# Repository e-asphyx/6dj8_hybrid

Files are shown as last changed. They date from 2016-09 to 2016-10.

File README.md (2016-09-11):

# DC coupled hybrid headphone amplifier
The input stage was inspired by Cavalli’s SOHA-II, but I have choose different output design. I use source follower loaded to Norton level shifter fed by op amp DC servo (inspired by TI’s LME49600 reference design) via current mirror to drive simple MOSFET source follower with SSC.

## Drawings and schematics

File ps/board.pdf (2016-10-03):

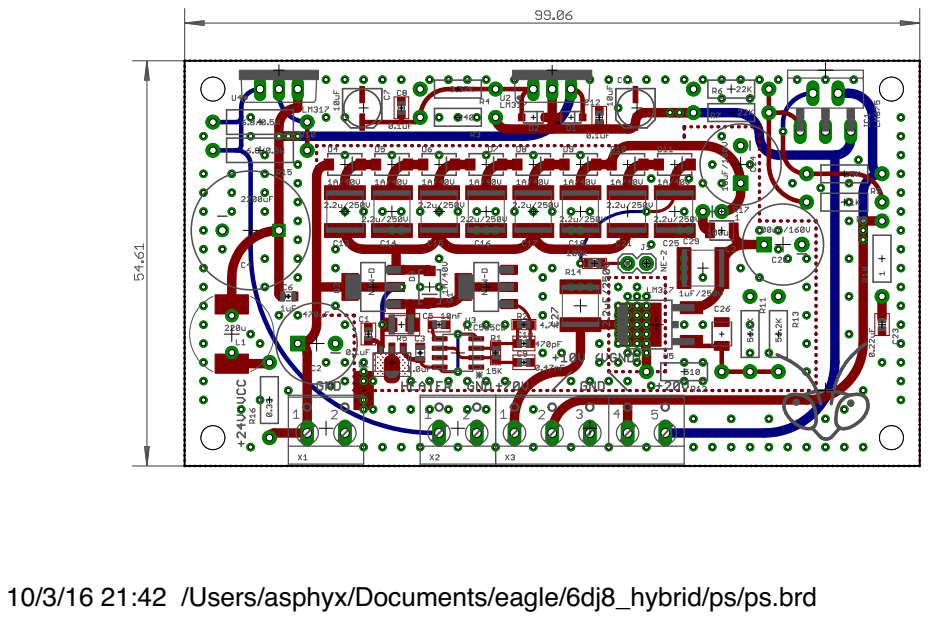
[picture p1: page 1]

10/3/16 21:42 /Users/asphyx/Documents/eagle/6dj8_hybrid/ps/ps.brd

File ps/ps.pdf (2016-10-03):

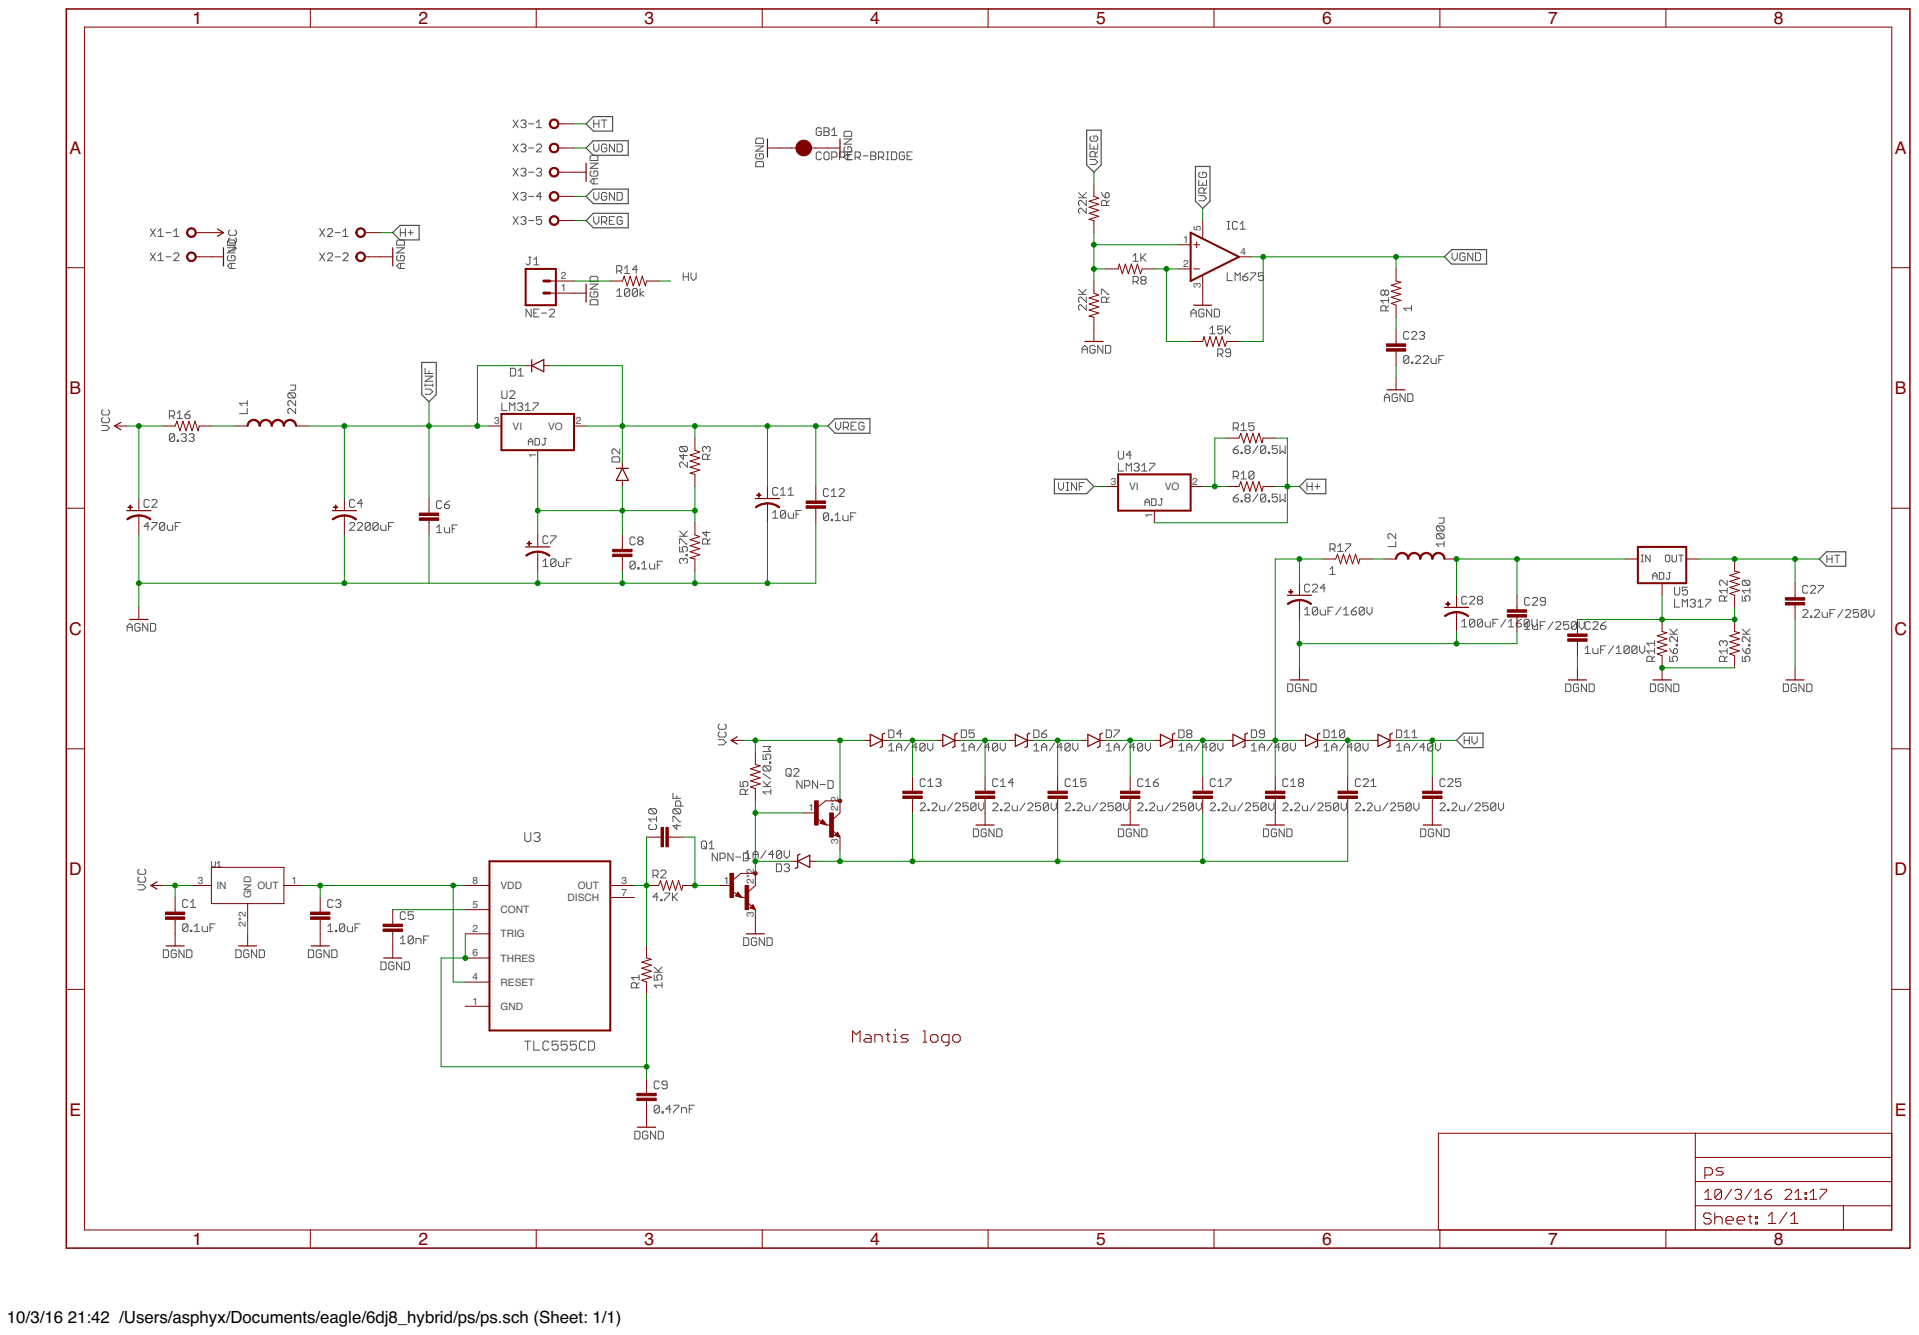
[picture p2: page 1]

10/3/16 21:42 /Users/asphyx/Documents/eagle/6dj8_hybrid/ps/ps.sch (Sheet: 1/1)

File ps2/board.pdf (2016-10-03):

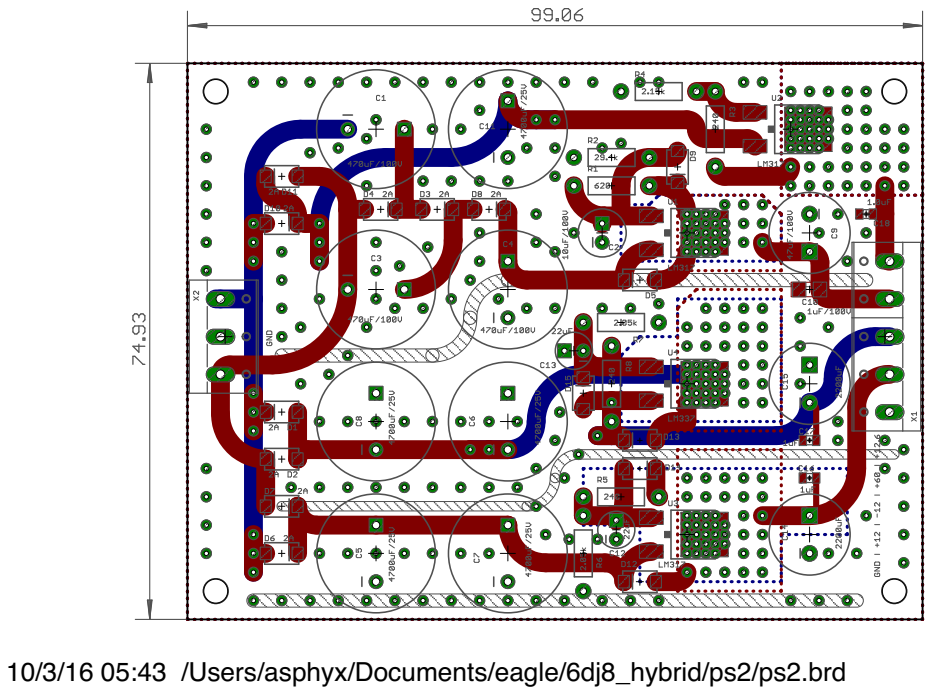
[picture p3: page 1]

10/3/16 05:43 /Users/asphyx/Documents/eagle/6dj8_hybrid/ps2/ps2.brd

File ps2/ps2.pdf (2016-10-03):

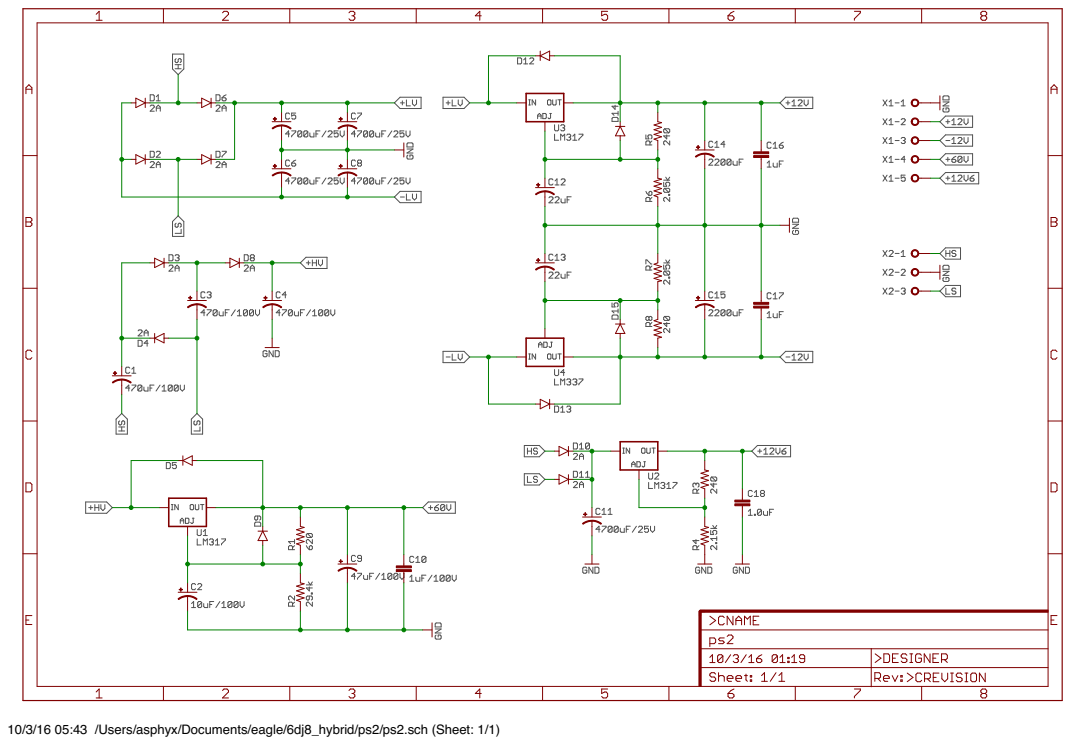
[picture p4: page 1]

10/3/16 05:43 /Users/asphyx/Documents/eagle/6dj8_hybrid/ps2/ps2.sch (Sheet: 1/1)

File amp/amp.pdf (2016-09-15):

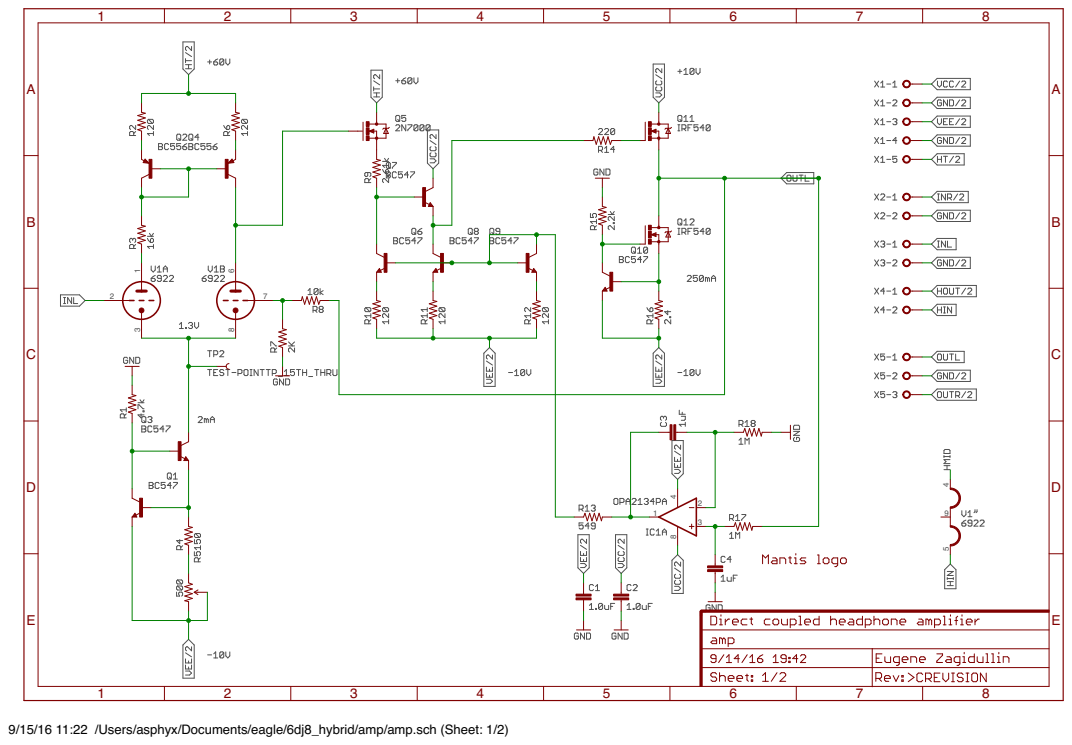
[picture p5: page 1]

9/15/16 11:22 /Users/asphyx/Documents/eagle/6dj8_hybrid/amp/amp.sch (Sheet: 1/2)

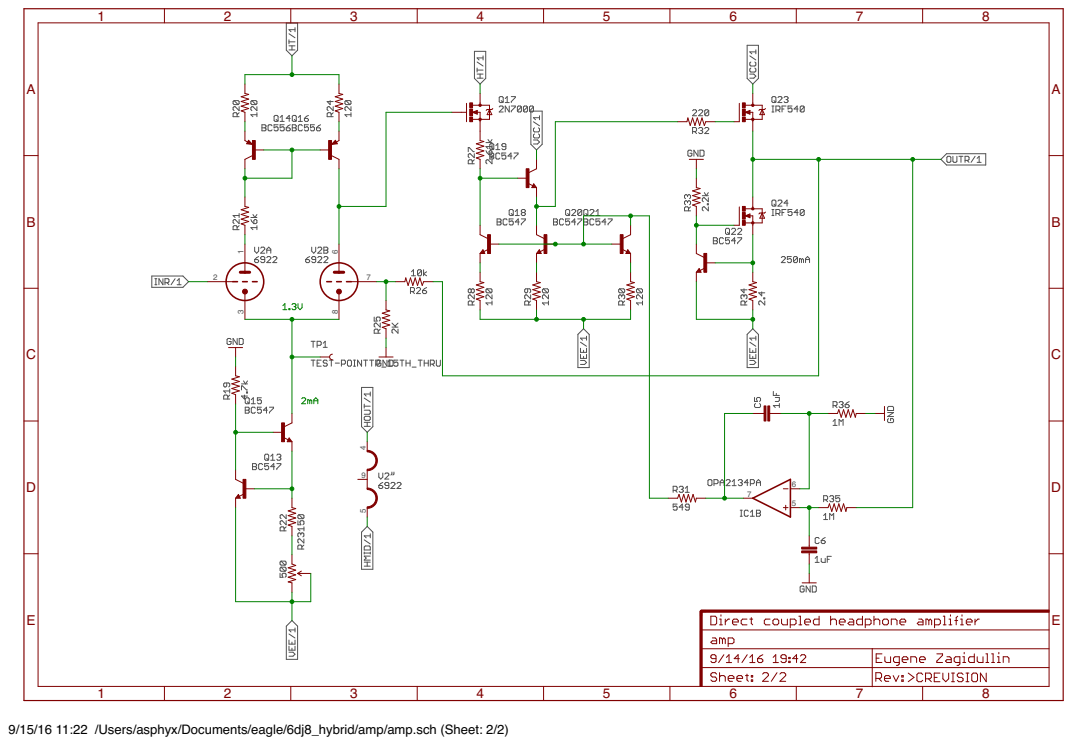
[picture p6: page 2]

9/15/16 11:22 /Users/asphyx/Documents/eagle/6dj8_hybrid/amp/amp.sch (Sheet: 2/2)

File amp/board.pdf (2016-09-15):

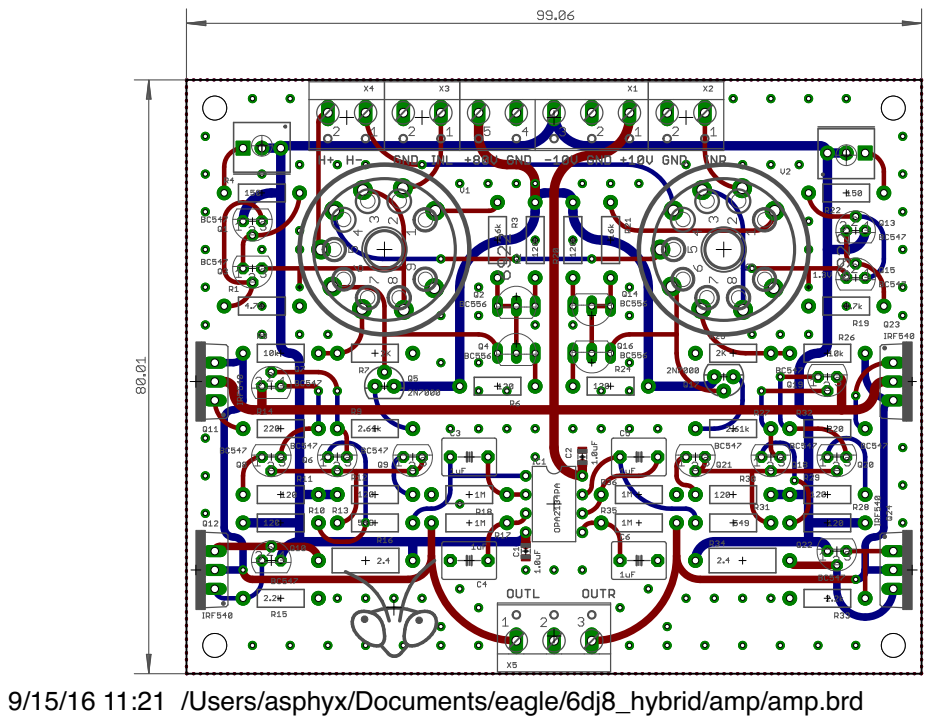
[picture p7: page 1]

9/15/16 11:21 /Users/asphyx/Documents/eagle/6dj8_hybrid/amp/amp.brd

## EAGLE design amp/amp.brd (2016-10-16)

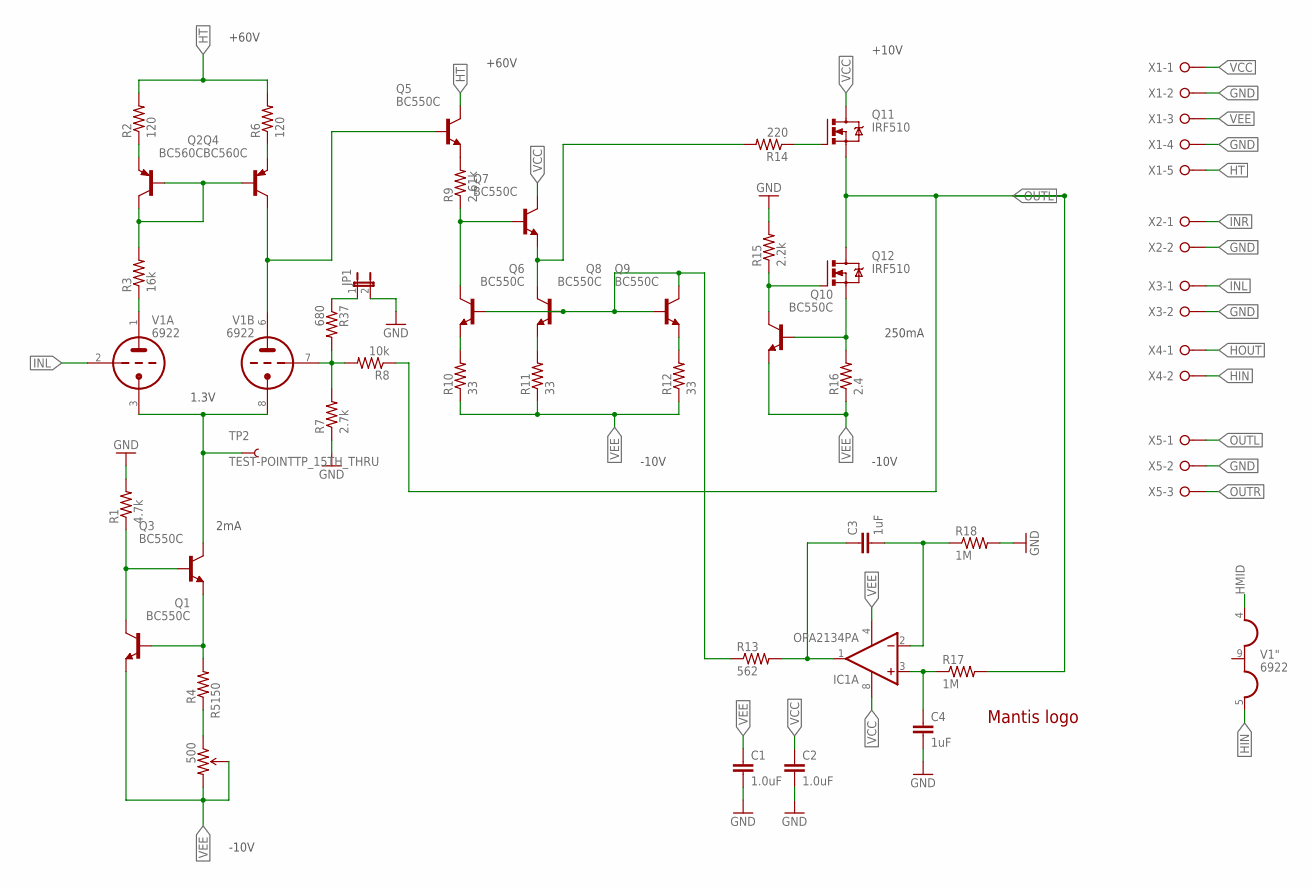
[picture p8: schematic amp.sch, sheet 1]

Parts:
C1, C2: 1.0uF; 0805-CAP
C3, C4: 1uF; C5B5
IC1: OPA2134PA; DIL08
JP1: JUMPER-2PTH; 1X02
LOGO1: LOGO-MANTIS
Q1, Q3, Q5, Q6, Q7, Q8, Q9, Q10: BC550C; TO92
Q2, Q4: BC560C; TO92-BENT
Q11, Q12: IRF510; TO220BV
R1: 4.7k; AXIAL-0.4
R2, R6: 120; AXIAL-0.4
R3: 16k; AXIAL-0.4
R4: 150; AXIAL-0.4
R5: 500; 3362U-2
R7: 2.7k; AXIAL-0.4
R8: 10k; AXIAL-0.4
R9: 2.61k; AXIAL-0.4
R10, R11, R12: 33; AXIAL-0.4
R13: 562; AXIAL-0.4
R14: 220; AXIAL-0.4
R15: 2.2k; AXIAL-0.4
R16: 2.4; AXIAL-0.5
R17, R18: 1M; AXIAL-0.4
R37: 680; AXIAL-0.4
TP2: TEST-POINTTP_15TH_THRU; TP_15TH
V1: 6922; NOVAL
X1: W237-05P; W237-5P
X2, X3, X4: W237-02P; W237-132
X5: W237-3E

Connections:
GND: C1.2, C2.2, C4.2, JP1.2, R1.P$2 (2), R7.P$1 (1), R15.P$2 (2), R18.P$2 (2), X1.2, X1.4, X2.2, X3.2, X5.2; also elsewhere on the board
HIN: V1.5 (H3), X4.2
HMID: V1.4 (H1); also elsewhere on the board
HOUT: X4.1; also elsewhere on the board
HT: Q5.3 (C), R2.P$2 (2), R6.P$2 (2), X1.5; also elsewhere on the board
INL: V1.2 (TG), X3.1
INR: X2.1; also elsewhere on the board
unnamed: Q3.3 (C), TP2.P$1, V1.3 (TK), V1.8 (TK)
unnamed: Q2.1 (C), Q2.2 (B), Q4.2 (B), R3.P$2 (2)
unnamed: Q2.3 (E), R2.P$1 (1)
unnamed: Q4.1 (C), Q5.2 (B), V1.6 (TA)
unnamed: R3.P$1 (1), V1.1 (TA)
unnamed: Q4.3 (E), R6.P$1 (1)
unnamed: Q1.2 (B), Q3.1 (E), R4.P$2 (2)
unnamed: Q1.3 (C), Q3.2 (B), R1.P$1 (1)
unnamed: R7.P$2 (2), R8.P$2 (2), R37.P$2 (2), V1.7 (TG)
unnamed: Q6.2 (B), Q8.2 (B), Q9.2 (B), Q9.3 (C), R13.P$1 (1)
unnamed: Q6.1 (E), R10.P$2 (2)
unnamed: Q9.1 (E), R12.P$2 (2)
unnamed: Q5.1 (E), R9.P$2 (2)
unnamed: Q10.3 (C), Q12.G, R15.P$1 (1)
unnamed: Q10.2 (B), Q12.S, R16.P$2 (2)
unnamed: C3.2, IC1.2 (-IN), R18.P$1 (1)
unnamed: C4.1, IC1.3 (+IN), R17.P$1 (1)
unnamed: C3.1, IC1.1 (OUT), R13.P$2 (2)
unnamed: Q8.1 (E), R11.P$2 (2)
unnamed: R4.P$1 (1), R5.1 (CCW)
unnamed: Q11.G, R14.P$1 (1)
unnamed: Q6.3 (C), Q7.2 (B), R9.P$1 (1)
unnamed: Q7.1 (E), Q8.3 (C), R14.P$2 (2)
unnamed: JP1.1, R37.P$1 (1)
OUTL: Q11.S, Q12.D, R8.P$1 (1), R17.P$2 (2), X5.1
OUTR: X5.3; also elsewhere on the board
VCC: C2.1, IC1.8 (V+), Q7.3 (C), Q11.D, X1.1; also elsewhere on the board
VEE: C1.1, IC1.4 (V-), Q1.1 (E), Q10.1 (E), R5.2 (WIPER), R5.3 (CW), R10.P$1 (1), R11.P$1 (1), R12.P$1 (1), R16.P$1 (1), X1.3; also elsewhere on the board

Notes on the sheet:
2mA
250mA
1.3V
+60V
+10V
-10V

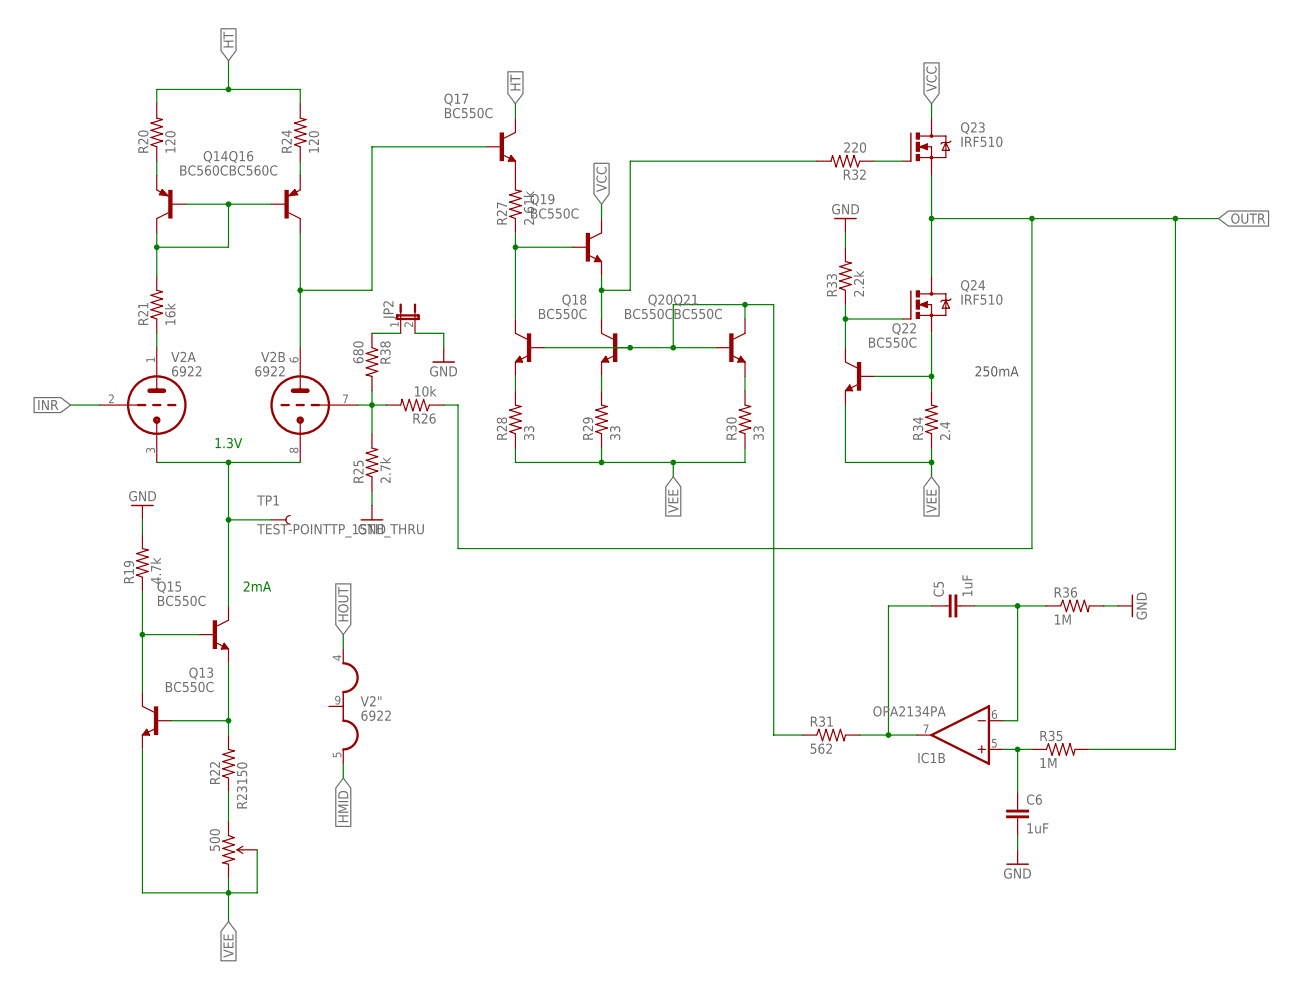
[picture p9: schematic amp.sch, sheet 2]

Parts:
C5, C6: 1uF; C5B5
IC1: OPA2134PA; DIL08
JP2: JUMPER-2PTH; 1X02
Q13, Q15, Q17, Q18, Q19, Q20, Q21, Q22: BC550C; TO92
Q14, Q16: BC560C; TO92-BENT
Q23, Q24: IRF510; TO220BV
R19: 4.7k; AXIAL-0.4
R20, R24: 120; AXIAL-0.4
R21: 16k; AXIAL-0.4
R22: 150; AXIAL-0.4
R23: 500; 3362U-2
R25: 2.7k; AXIAL-0.4
R26: 10k; AXIAL-0.4
R27: 2.61k; AXIAL-0.4
R28, R29, R30: 33; AXIAL-0.4
R31: 562; AXIAL-0.4
R32: 220; AXIAL-0.4
R33: 2.2k; AXIAL-0.4
R34: 2.4; AXIAL-0.5
R35, R36: 1M; AXIAL-0.4
R38: 680; AXIAL-0.4
TP1: TEST-POINTTP_15TH_THRU; TP_15TH
V2: 6922; NOVAL

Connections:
GND: C6.2, JP2.2, R19.P$2 (2), R25.P$1 (1), R33.P$2 (2), R36.P$2 (2); also elsewhere on the board
HMID: V2.5 (H3); also elsewhere on the board
HOUT: V2.4 (H1); also elsewhere on the board
HT: Q17.3 (C), R20.P$2 (2), R24.P$2 (2); also elsewhere on the board
INR: V2.2 (TG); also elsewhere on the board
unnamed: Q18.3 (C), Q19.2 (B), R27.P$1 (1)
unnamed: Q15.3 (C), TP1.P$1, V2.3 (TK), V2.8 (TK)
unnamed: Q14.1 (C), Q14.2 (B), Q16.2 (B), R21.P$2 (2)
unnamed: Q16.1 (C), Q17.2 (B), V2.6 (TA)
unnamed: R21.P$1 (1), V2.1 (TA)
unnamed: Q14.3 (E), R20.P$1 (1)
unnamed: Q16.3 (E), R24.P$1 (1)
unnamed: Q13.2 (B), Q15.1 (E), R22.P$2 (2)
unnamed: Q13.3 (C), Q15.2 (B), R19.P$1 (1)
unnamed: Q18.2 (B), Q20.2 (B), Q21.2 (B), Q21.3 (C), R31.P$1 (1)
unnamed: Q18.1 (E), R28.P$2 (2)
unnamed: Q21.1 (E), R30.P$2 (2)
unnamed: Q19.1 (E), Q20.3 (C), R32.P$2 (2)
unnamed: Q22.3 (C), Q24.G, R33.P$1 (1)
unnamed: Q22.2 (B), Q24.S, R34.P$2 (2)
unnamed: R25.P$2 (2), R26.P$2 (2), R38.P$2 (2), V2.7 (TG)
unnamed: C5.2, IC1.6 (-IN), R36.P$1 (1)
unnamed: C6.1, IC1.5 (+IN), R35.P$1 (1)
unnamed: C5.1, IC1.7 (OUT), R31.P$2 (2)
unnamed: R22.P$1 (1), R23.1 (CCW)
unnamed: Q23.G, R32.P$1 (1)
unnamed: Q17.1 (E), R27.P$2 (2)
unnamed: Q20.1 (E), R29.P$2 (2)
unnamed: JP2.1, R38.P$1 (1)
OUTR: Q23.S, Q24.D, R26.P$1 (1), R35.P$2 (2); also elsewhere on the board
VCC: Q19.3 (C), Q23.D; also elsewhere on the board
VEE: Q13.1 (E), Q22.1 (E), R23.2 (WIPER), R23.3 (CW), R28.P$1 (1), R29.P$1 (1), R30.P$1 (1), R34.P$1 (1); also elsewhere on the board

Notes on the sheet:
2mA
250mA
1.3V

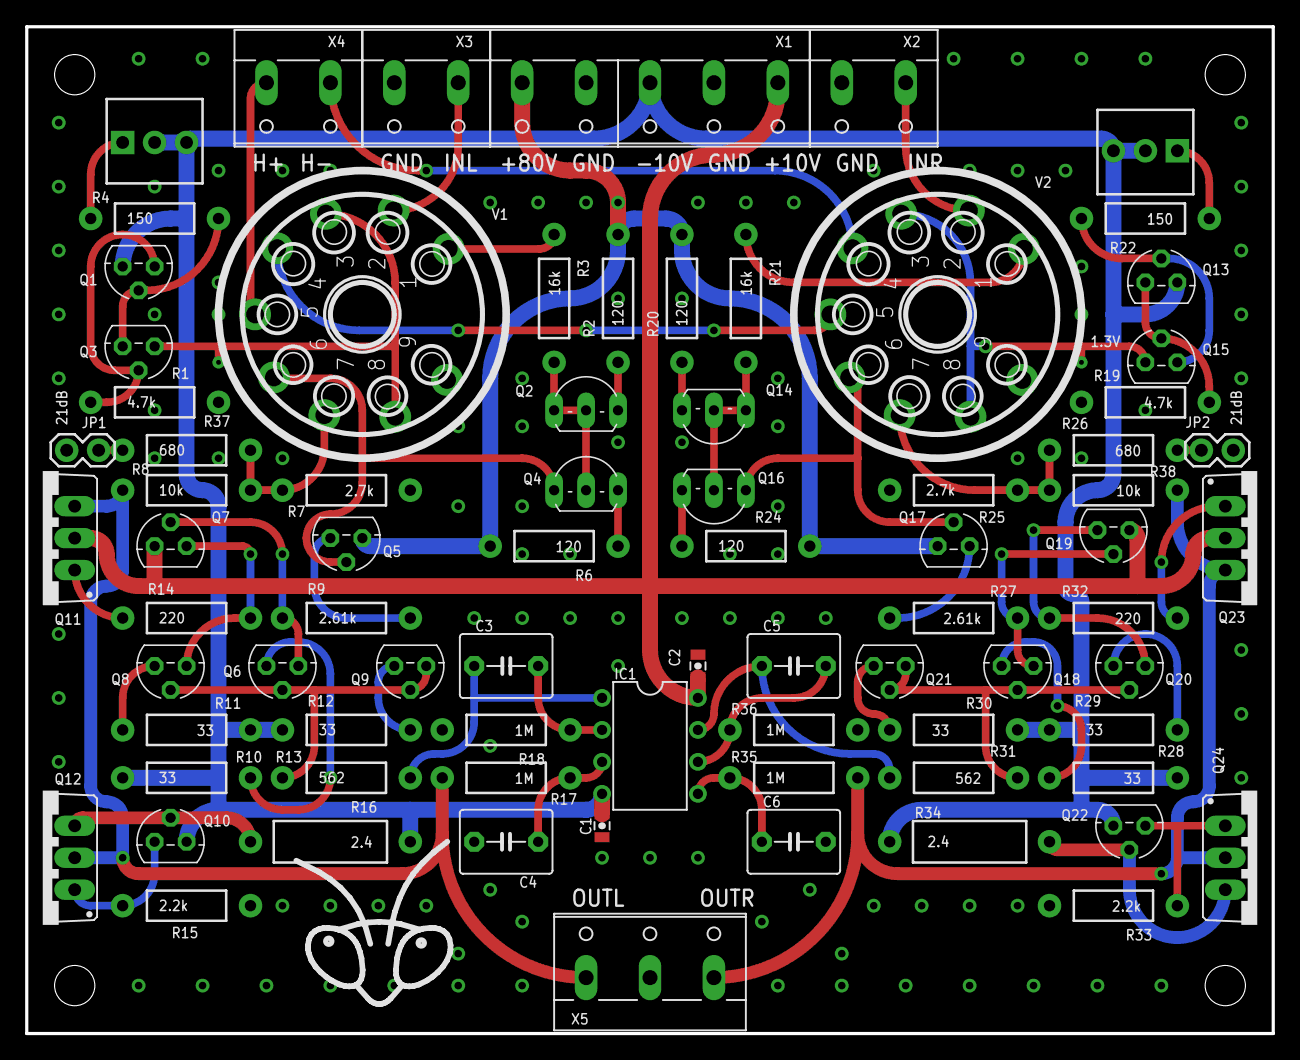
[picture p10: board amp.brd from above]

Board: 2 copper layers, 99.1 x 80.0 mm, 81 parts (0 on the bottom side), 59 nets.

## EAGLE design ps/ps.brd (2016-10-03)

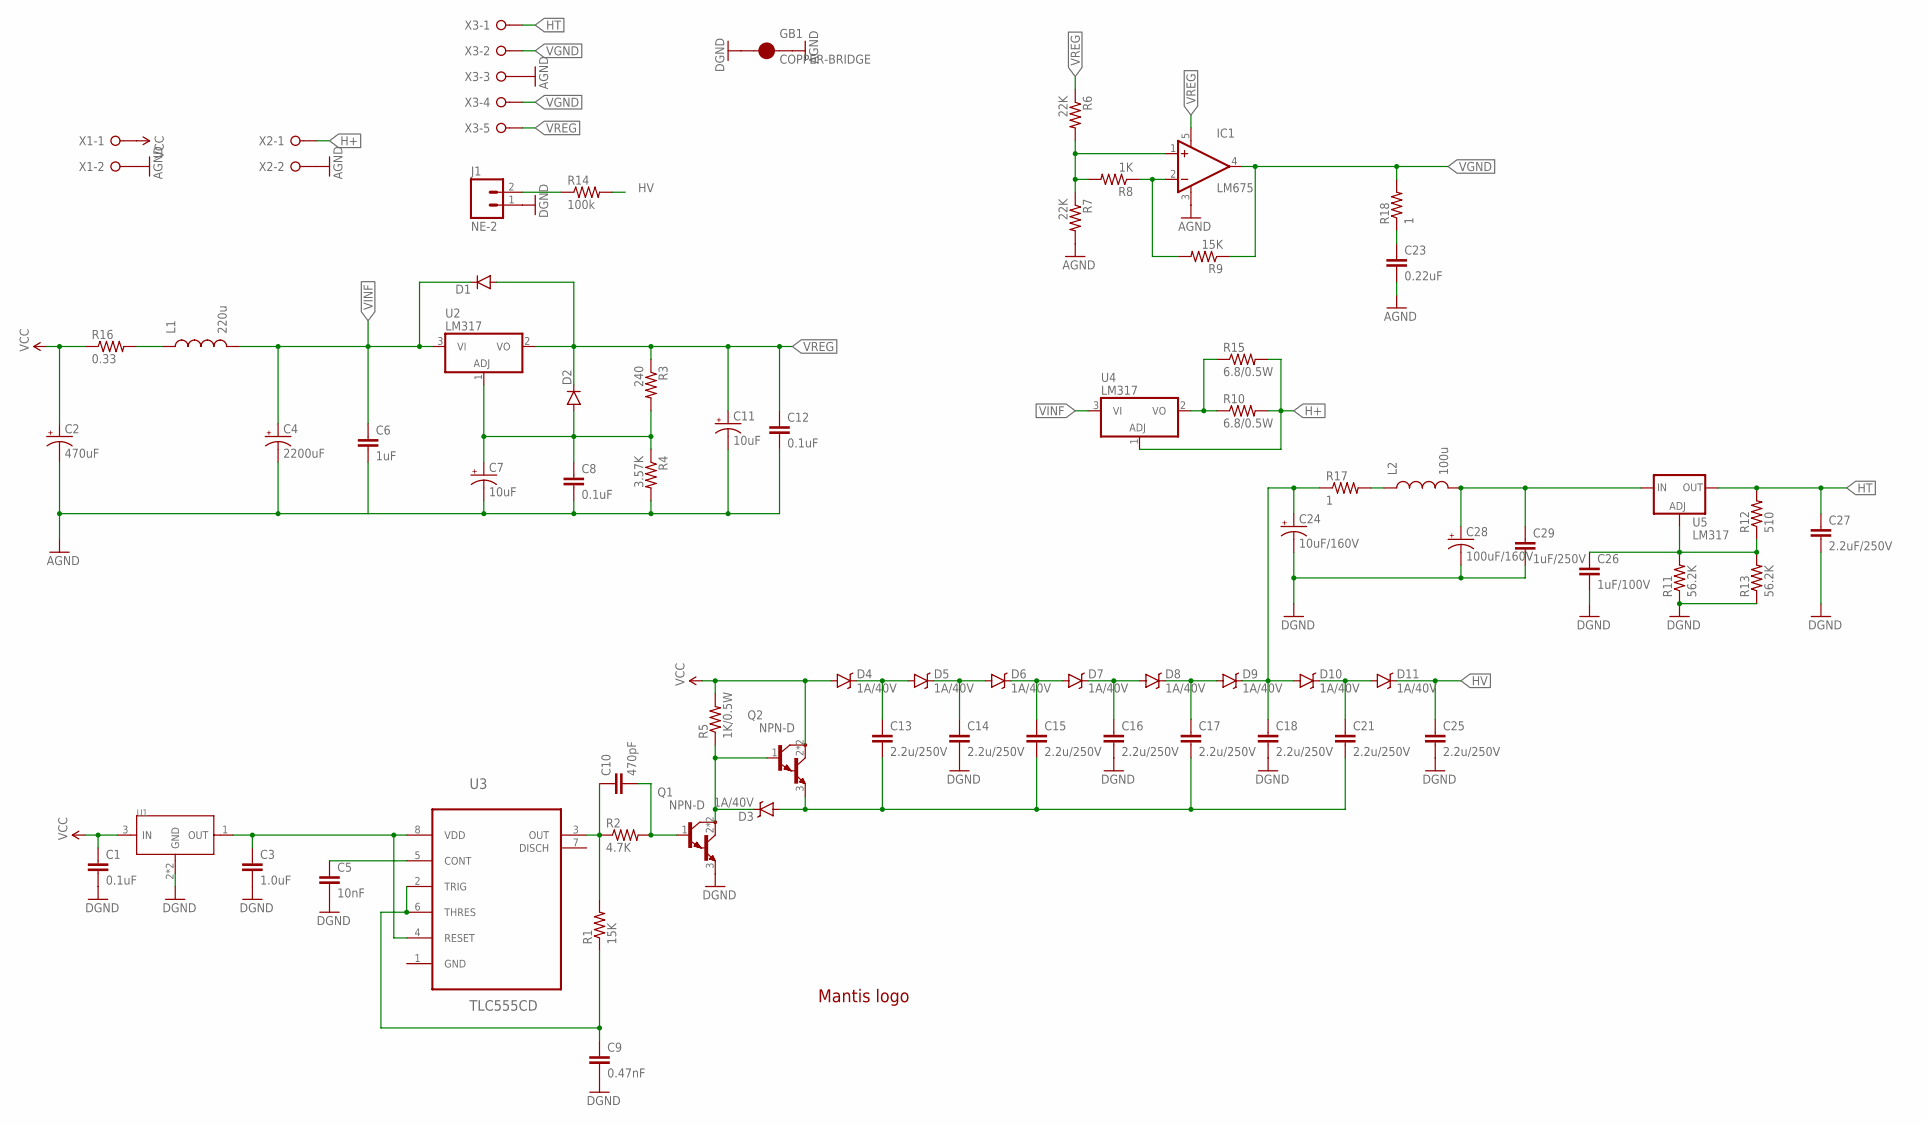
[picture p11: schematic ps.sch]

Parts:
C1, C8, C12: 0.1uF; 0603-CAP
C2: 470uF; CPOL-RADIAL-1000UF-25V
C3: 1.0uF; 0805-CAP
C4: 2200uF; CPOL-RADIAL-1000UF-63V
C5: 10nF; 0603-CAP
C6: 1uF; 0805-CAP
C7, C11: 10uF; PANASONIC_C
C9: 0.47nF; 0603-CAP
C10: 470pF; 0603-CAP
C13, C14, C15, C16, C17, C18, C21, C25: 2.2u/250V; C2220K
C23: 0.22uF; 0603-CAP
C24: 10uF/160V; CPOL-RADIAL-1000UF-25V
C26: 1uF/100V; 1210
C27: 2.2uF/250V; C2220K
C28: 100uF/160V; CPOL-RADIAL-1000UF-25V
C29: 1uF/250V; C2220K
D1, D2: DIODESOD123; SOD-123
D3, D4, D5, D6, D7, D8, D9, D10, D11: 1A/40V; SMA-DIODE
GB1: COPPER-BRIDGE
IC1: LM675; TO220-5
J1: NE-2; 1X02
L1: 220u; NR10050T-PTH-ADD
L2: 100u; 1210; MOUSER_PRICE 0.168
LOGO1: LOGO-MANTIS
Q1, Q2: NPN-D; SOT223
R1: 15K; 0603-RES
R2: 4.7K; 0603-RES
R3: 240; AXIAL-0.4
R4: 3.57K; AXIAL-0.4
R5: 1K/0.5W; R1210W
R6, R7: 22K; AXIAL-0.4
R8: 1K; AXIAL-0.4
R9: 15K; AXIAL-0.4
R10, R15: 6.8/0.5W; AXIAL-0.5
R11, R13: 56.2K; AXIAL-0.4
R12: 510; AXIAL-0.4
R14: 100k; 0603-RES
R16: 0.33; AXIAL-0.4
R17: 1; AXIAL-0.1
R18: 1; AXIAL-0.4
U1: L78L12ACUTR; SOT-89
U2, U4: LM317; TO220BV
U3: TLC555CD; SOIC127P600X175-8N
U5: LM317; V-REG_DPACK
X1, X2: W237-02P; W237-132
X3: W237-05P; W237-5P

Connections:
555CONT: C5.1, U3.5 (CONT)
555OUT: C10.1, R1.2, R2.1, U3.3 (OUT)
555TRIG: C9.1, R1.1, U3.2 (TRIG), U3.6 (THRES)
555VDD: C3.1, U1.1 (OUT), U3.4 (RESET), U3.8 (VDD)
AGND: C2.-, C4.2 (-), C6.2, C7.-, C8.2, C11.-, C12.2, C23.2, GB1.P$2.1 (2), GB1.P$2.2 (2), IC1.3 (V-), R4.P$2 (2), R7.P$2 (2), X1.2, X2.2, X3.3
GND: C1.2, C3.2, C5.2, C9.2, C14.2, C16.2, C18.2, C24.-, C25.2, C26.2, C27.2, C28.-, C29.2, GB1.P$1.1 (1), GB1.P$1.2 (1), J1.1, Q1.3 (E), R11.P$1 (1), R13.P$1 (1), U1.2 (GND), U1.PAD (GND)
H+: R10.P$2 (2), R15.P$2 (2), U4.1 (ADJ), X2.1
HT: C27.1, R12.P$2 (2), U5.4 (OUT), X3.1
HV: C25.1, D11.C, R14.2
unnamed: D3.C, Q1.2 (C), Q1.4 (C), Q2.1 (B), R5.1
unnamed: IC1.1 (+IN), R6.P$2 (2), R7.P$1 (1), R8.P$2 (2)
unnamed: IC1.2 (-IN), R8.P$1 (1), R9.P$2 (2)
unnamed: C21.1, D10.C, D11.A
unnamed: J1.2, R14.1
unnamed: C13.1, D4.C, D5.A
unnamed: C28.+, C29.1, L2.2, U5.3 (IN)
unnamed: R10.P$1 (1), R15.P$1 (1), U4.2 (VO)
unnamed: L1.P$1 (1), L1.P$1.1 (1), R16.P$2 (2)
unnamed: C10.2, Q1.1 (B), R2.2
unnamed: C14.1, D5.C, D6.A
unnamed: C15.1, D6.C, D7.A
unnamed: C16.1, D7.C, D8.A
unnamed: C17.1, D8.C, D9.A
unnamed: C18.1, C24.+, D9.C, D10.A, R17.P$1 (1)
unnamed: L2.1, R17.P$2 (2)
unnamed: C23.1, R18.P$1 (1)
unnamed: C26.1, R11.P$2 (2), R12.P$1 (1), R13.P$2 (2), U5.1 (ADJ)
PUMPIN: C13.2, C15.2, C17.2, C21.2, D3.A, Q2.3 (E)
REGADJ: C7.+, C8.1, D2.A, R3.P$2 (2), R4.P$1 (1), U2.1 (ADJ)
VCC: C1.1, C2.+, D4.A, Q2.2 (C), Q2.4 (C), R5.2, R16.P$1 (1), U1.3 (IN), X1.1
VGND: IC1.4 (OUT), R9.P$1 (1), R18.P$2 (2), X3.2, X3.4
VINF: C4.1 (+), C6.1, D1.C, L1.P$2 (2), L1.P$2.1 (2), U2.3 (VI), U4.3 (VI)
VREG: C11.+, C12.1, D1.A, D2.C, IC1.5 (V+), R3.P$1 (1), R6.P$1 (1), U2.2 (VO), X3.5

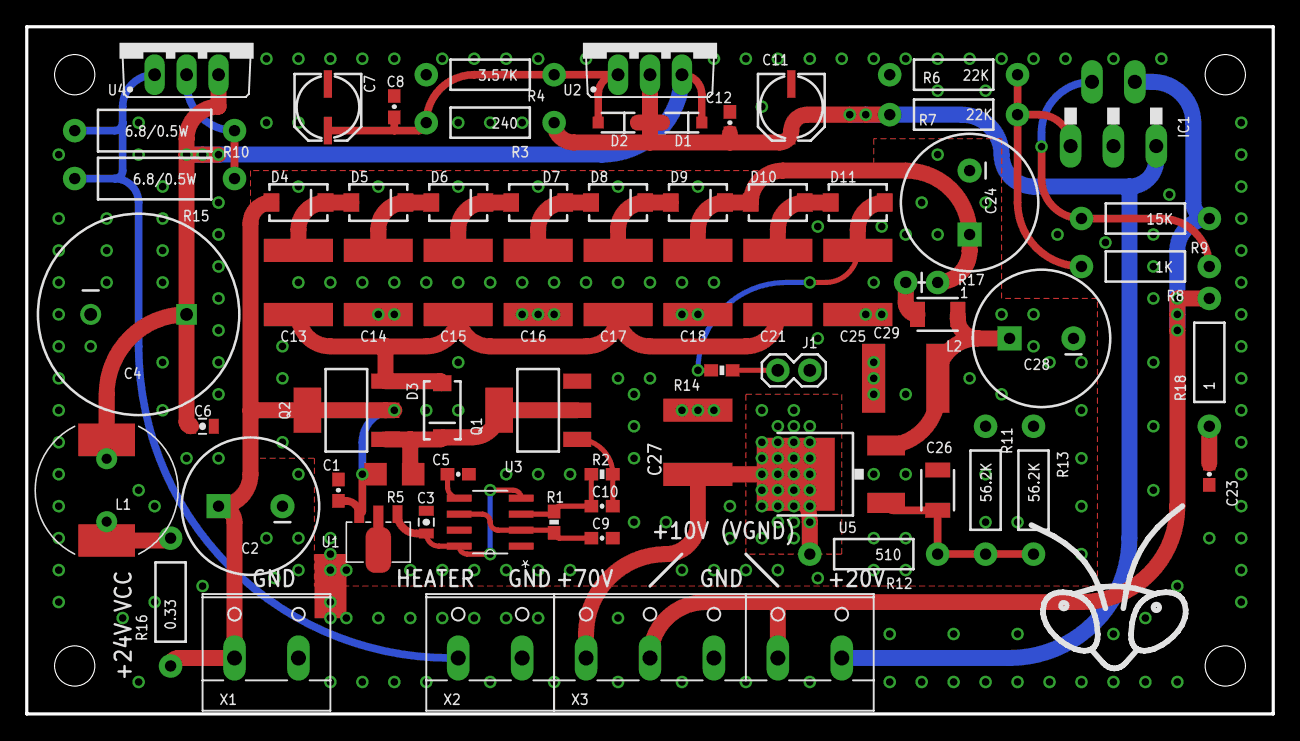
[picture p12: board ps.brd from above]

Board: 2 copper layers, 99.1 x 54.6 mm, 71 parts (0 on the bottom side), 33 nets.

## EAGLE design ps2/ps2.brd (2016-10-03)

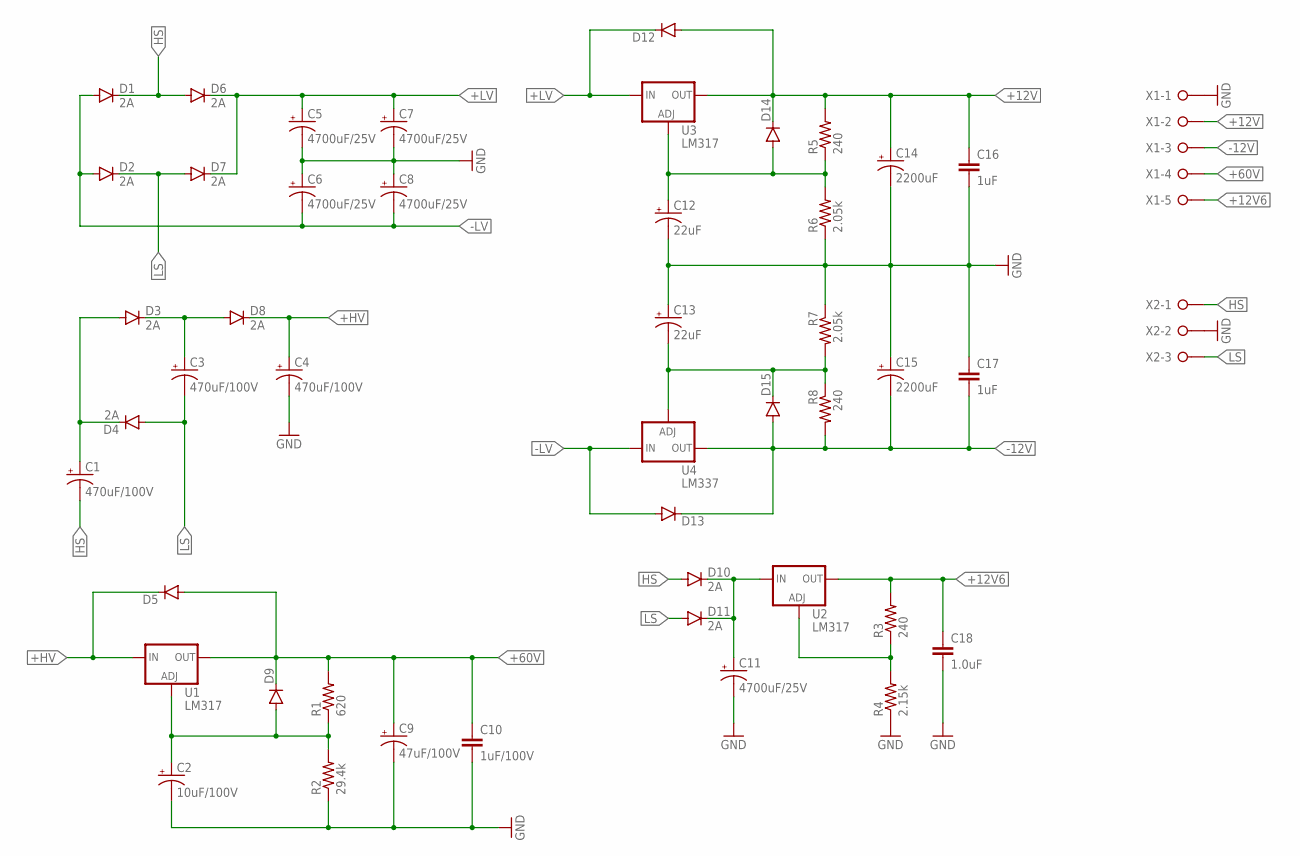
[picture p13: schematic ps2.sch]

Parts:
C1, C3, C4: 470uF/100V; CPOL-RADIAL-1000UF-63V
C2: 10uF/100V; CPOL-RADIAL-100UF-25V
C5, C6, C7, C8, C11: 4700uF/25V; CPOL-RADIAL-1000UF-63V
C9: 47uF/100V; CPOL-RADIAL-1000UF-25V
C10: 1uF/100V; C1206
C12, C13: 22uF; CPOL-RADIAL-10UF-25V
C14, C15: 2200uF; CPOL-RADIAL-1000UF-25V
C16, C17: 1uF; 0805-CAP
C18: 1.0uF; 0805-CAP
D1, D2, D3, D4, D6, D7, D8, D10, D11: 2A; SMA-DIODE
D5, D9, D12, D13, D14, D15: DIODESMA; SMA-DIODE
R1: 620; AXIAL-0.4
R2: 29.4k; AXIAL-0.4
R3, R5, R8: 240; AXIAL-0.4
R4: 2.15k; AXIAL-0.4
R6, R7: 2.05k; AXIAL-0.4
U1, U2, U3: LM317; V-REG_DPACK
U4: LM337; V-REG_DPACK
X1: W237-05P; W237-5P
X2: W237-3E

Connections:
+12V: C14.+, C16.1, D12.A, D14.C, R5.P$2 (2), U3.4 (OUT), X1.2
+12V6: C18.1, R3.P$2 (2), U2.4 (OUT), X1.5
+60V: C9.+, C10.1, D5.A, D9.C, R1.P$2 (2), U1.4 (OUT), X1.4
+HV: C4.1 (+), D5.C, D8.C, U1.3 (IN)
+LV: C5.1 (+), C7.1 (+), D6.C, D7.C, D12.C, U3.3 (IN)
-12V: C15.-, C17.2, D13.C, D15.A, R8.P$2 (2), U4.3 (OUT), X1.3
-LV: C6.2 (-), C8.2 (-), D1.A, D2.A, D13.A, U4.2 (IN)
GND: C2.2 (-), C4.2 (-), C5.2 (-), C6.1 (+), C7.2 (-), C8.1 (+), C9.-, C10.2, C11.2 (-), C12.2 (-), C13.1 (+), C14.-, C15.+, C16.2, C17.1, C18.2, R2.P$1 (1), R4.P$1 (1), R6.P$1 (1), R7.P$1 (1), X1.1, X2.2
HS: C1.2 (-), D1.C, D6.A, D10.A, X2.1
LS: C3.2 (-), D2.C, D4.A, D7.A, D11.A, X2.3
unnamed: C1.1 (+), D3.A, D4.C
unnamed: C3.1 (+), D3.C, D8.A
unnamed: C13.2 (-), D15.C, R7.P$2 (2), R8.P$1 (1), U4.1 (ADJ)
unnamed: C12.1 (+), D14.A, R5.P$1 (1), R6.P$2 (2), U3.1 (ADJ)
unnamed: C2.1 (+), D9.A, R1.P$1 (1), R2.P$2 (2), U1.1 (ADJ)
unnamed: R3.P$1 (1), R4.P$2 (2), U2.1 (ADJ)
unnamed: C11.1 (+), D10.C, D11.C, U2.3 (IN)

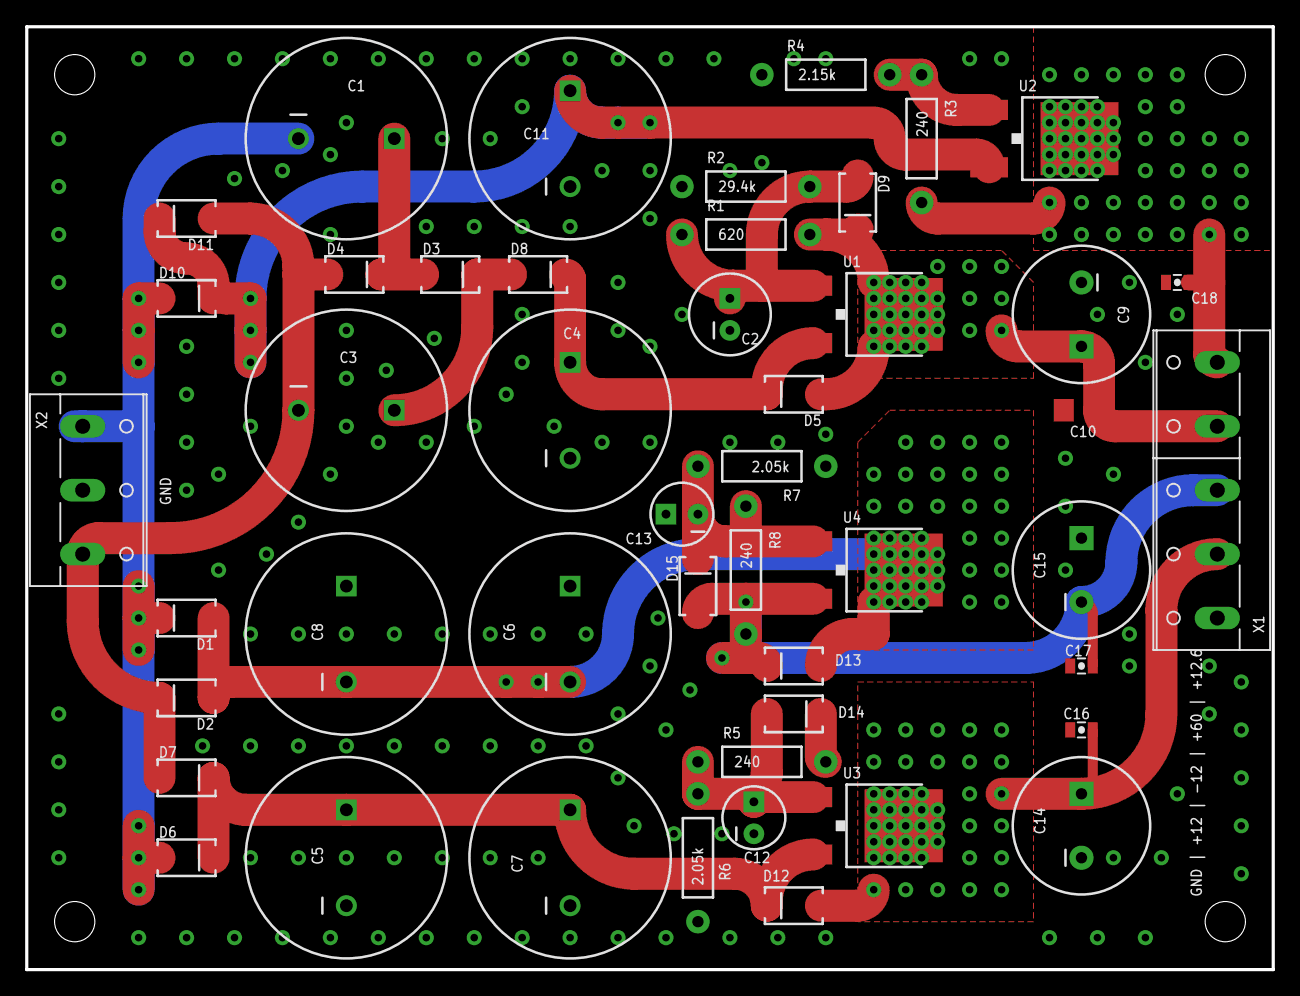
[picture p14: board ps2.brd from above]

Board: 2 copper layers, 99.1 x 74.9 mm, 47 parts (0 on the bottom side), 17 nets.

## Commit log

2016-09-02 Back to 60V supply
    [amp.brd, amp.sch, ps.brd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]
2016-09-06 HV for neon bulb
    [amp.brd, amp.sch, ps.brd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]
2016-09-06 Some tweaks
    [amp.brd, ps.brd, ps.sch]
2016-09-09 PSU tweaked
    [ps.brd, ps.sch]
2016-09-09 More filtering
    [ps.brd, ps.sch]
2016-09-10 Gate resistors added
    [amp.brd, amp.sch]
2016-09-10 Back to IRF5xx
    [amp.brd, amp.sch]
2016-09-10 HT filter added
    [amp.brd, amp.sch, ps.brd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]
2016-09-10 Unneeded resistors
    [ps.brd, ps.sch]
2016-09-11 PS rerouted
    [ps.brd, ps.sch]
2016-09-11 Separated grounds
    [ps.brd, ps.sch]
2016-09-12 More tweaks
    [amp.brd, amp.sch, ps.brd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]
2016-09-13 Small bypass cap added
    [amp.brd, amp.sch]
2016-09-13 High frequency snubber
    [amp.brd, amp.sch]
2016-09-15 MOSFET driver stage
    [amp.brd, amp.sch]
2016-09-23 Gain switching jumper
    [amp.brd, amp.sch]
2016-10-02 AC PSU done
    [ps2.brd, ps2.sch]
2016-10-02 Small tweak
    [ps2.brd, ps2.sch]
2016-10-03 LC damping resistors added to PS
    [ps.brd, ps.sch]
2016-10-03 Unneeded caps removed
    [ps.brd, ps.sch]
2016-10-08 CM degeneration values lowered
    [amp.brd, amp.sch]
2016-10-16 Some components changed
    [amp.brd, amp.sch]

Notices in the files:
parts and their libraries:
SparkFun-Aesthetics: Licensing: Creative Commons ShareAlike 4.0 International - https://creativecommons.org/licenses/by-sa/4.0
